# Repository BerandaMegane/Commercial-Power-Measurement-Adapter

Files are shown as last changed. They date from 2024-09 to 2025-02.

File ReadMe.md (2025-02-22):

# Commercial-Power-Measurement-Adapter

部屋のコンセントから出ている商用電源（AC100V）の周波数と電圧を測定するアダプタをマイコンで製作しました。  
Windows PC や Raspberry Pi へアダプタを USB 接続すると、仮想 COM ポートとして認識され、測定値を取得することができます。

筐体に収められた基板
回路基板

回路・マイコンプログラムは次のサイトを参考にしています。~~というかアレンジして作ってみた結果、劣化コピーになりました。~~  
* ChaN氏 [ELM - 電圧周波数測定アダプタ](http://elm-chan.org/works/lvfm/report_j.html)

Qiita にて解説しています。
* Qiita - [電源周波数測定アダプタを真似して作ってみた](https://qiita.com/BerandaMegane/items/4fd927695e5ca32714c5)

このアダプタから電源周波数の情報を取得し、可視化するプログラムはこちらです。
* [BerandaMegane/Power-Monitoring-Agent](https://github.com/BerandaMegane/Power-Monitoring-Agent)

以降は各ディレクトリの中身を解説しています。

## Circuit design 回路設計 

回路図や LTSpice シミュレーションファイル (.asc) など、アダプタの回路設計に関するファイルを置いています。  
作図ソフトウェアは BSch3V です。

* BSch3V - https://www.suigyodo.com/online/schsoft.htm
* LTSpice - https://www.analog.com/jp/resources/design-tools-and-calculators/ltspice-simulator.html

回路設計のバージョンは2つあります。

* [ver1](https://github.com/BerandaMegane/Commercial-Power-Measurement-Adapter/tree/main/CircuitDesign/ver1)
  * 製作したバージョンですが、修正したい点がいくつかあります。
* [ver2](https://github.com/BerandaMegane/Commercial-Power-Measurement-Adapter/tree/main/CircuitDesign/ver2)
  * 修正バージョンですが、製作していません。

## Board design 基板設計

ユニバーサル基板（秋月電子通商 B 基板）で製作しました。部品の配置に関するファイルを置いています。画像に載っていない部品も多いので、あんまり参考にはなりません。  
作図ソフトウェアは marmelo です。

* marmelo - https://motchy99.blog.fc2.com/blog-entry-70.html

## Program ATmega328P マイコンプログラム

制御マイコンには AVR ATmega328P を使用しており、当初は、Atmel Studio (Microchip Studio) による AVR GCC プロジェクトで製作していましたが、後日 Rust (avr-hal) に書き直しています。  
詳細は各ディレクトリの中を参考にしてください。

ビルド済みバイナリ (.elf) を使ってプログラムを書き込むときは、次を参考にしてください。

1. [Releases](https://github.com/BerandaMegane/Commercial-Power-Measurement-Adapter/releases) からバイナリをダウンロードします。
1. AVR ライターを使用し、マイコンにバイナリを書き込みます。  
AVR ライターは Arduino があれば自作することもできます。

なお、ビルド済みバイナリは、公開している回路基板で動作させる前提であり、その他の条件は次の通りです。
* 動作クロック 20MHz
  * ヒューズビット: FF. D9, FF  
  https://www.engbedded.com/fusecalc?P=ATmega328P&V_LOW=0xFF&V_HIGH=0xD9&V_EXTENDED=0xFF&O_HEX=Apply+values
* シリアル通信
  * non-parity, stop-1bit, data-8bit, 19200bps 

* Atmel Studio - https://www.microchip.com/en-us/tools-resources/develop/microchip-studio
* avr-hal - https://github.com/Rahix/avr-hal

## STL 3Dプリンタ 筐体モデル

3Dプリンタで作った筐体です。

* [top.stl](./STL/top.stl)
* [bottom.stl](./STL/bottom.stl)

## License
This project is licensed under the MIT License, see the LICENSE file for details.

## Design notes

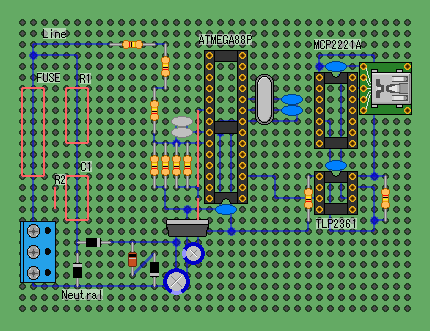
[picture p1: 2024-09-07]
BoardDesign/ver2/メイン基板_表面_ver2.bmp

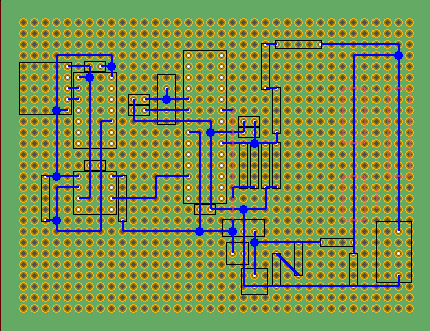
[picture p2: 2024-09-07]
BoardDesign/ver2/メイン基板_裏面_ver2.bmp

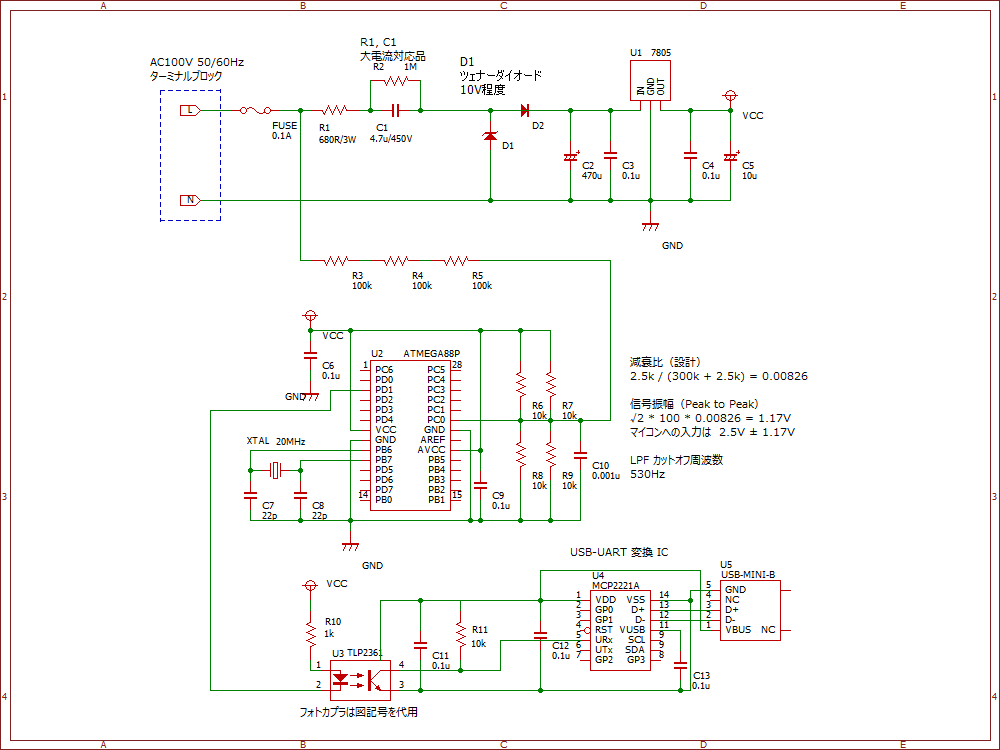
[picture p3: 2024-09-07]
CircuitDesign/ver2/circuit_ver2.png

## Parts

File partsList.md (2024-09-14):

# 部品リスト

## 基板その他
* 秋月電子 ユニバーサル基板 Bタイプ
  * https://akizukidenshi.com/catalog/g/g103230
* 2P ACコード(2Pプラグ/ハンダ仕上げコード) 1.8m
  * https://akizukidenshi.com/catalog/g/g100733/
* USBケーブル USB2.0 Type-Aオス⇔ミニBオス 1.5m A-miniB
  * https://akizukidenshi.com/catalog/g/g117014/

## 電源関係
特記事項なしは 1/4W 炭素被膜抵抗などの汎用品です。

* 20mm ヒューズホルダー マル信無線電機 MF-563
  * https://akizukidenshi.com/catalog/g/g114929/
* ガラス管ヒューズ MF51NR 250V0.2A 20mm
  * https://akizukidenshi.com/catalog/g/g107127/
* ターミナルブロック 2P 緑 縦 TB411-2-2-E-1
  * https://akizukidenshi.com/catalog/g/g106309/
* R1 不燃性酸化金属皮膜抵抗 3W220Ω
  * 回路図上は 680 Ω ですが、多少調整はできます。
  * https://akizukidenshi.com/catalog/g/g111020/
* C1 メタライズドポリプロピレンフィルムコンデンサー 4.7μF250V ルビコンMPS
  * https://akizukidenshi.com/catalog/g/g105982/
* D1 定電圧ダイオード(ツェナーダイオード) 5.6V1W RD5.6F
  * 回路図上は 10 V 程度のツェナー電圧が指定されていますが、低い電圧のものでも直列接続で 10 V 以上になれば問題ないと考えています。
  * https://akizukidenshi.com/catalog/g/g117082/
* D2 汎用整流用ダイオード 1000V1A 1N4007
  * https://akizukidenshi.com/catalog/g/g100934/
* U1 三端子レギュレーター 5V1.5A NJM7805FA
  * https://akizukidenshi.com/catalog/g/g108678/

## マイコン関係
* AVRマイコン ATMEGA328P-PU
  * https://akizukidenshi.com/catalog/g/g103142/
* 丸ピンICソケット (28P) 300mil
  * https://akizukidenshi.com/catalog/g/g101339
* クリスタル(水晶発振子) 20MHz
  * https://akizukidenshi.com/catalog/g/g108673/
* フォトカプラー GaAlAs赤外LED+フォトIC TLP2361
  * https://akizukidenshi.com/catalog/g/g111004/
* USB⇔シリアル変換IC MCP2221A-I/P
  * https://akizukidenshi.com/catalog/g/g113069/
* ブレッドボード用ミニBメスUSBコネクターDIP化キット
  * https://akizukidenshi.com/catalog/g/g105258/

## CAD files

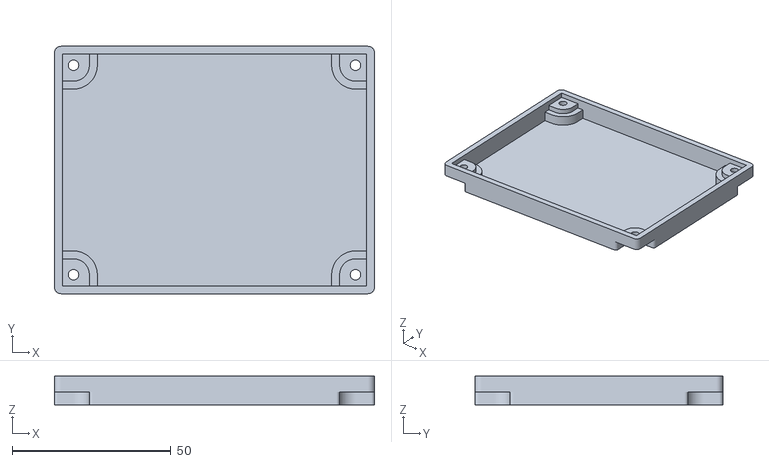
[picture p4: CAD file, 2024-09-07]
STL/bottom.stl
100.9 x 78.0 x 9.00

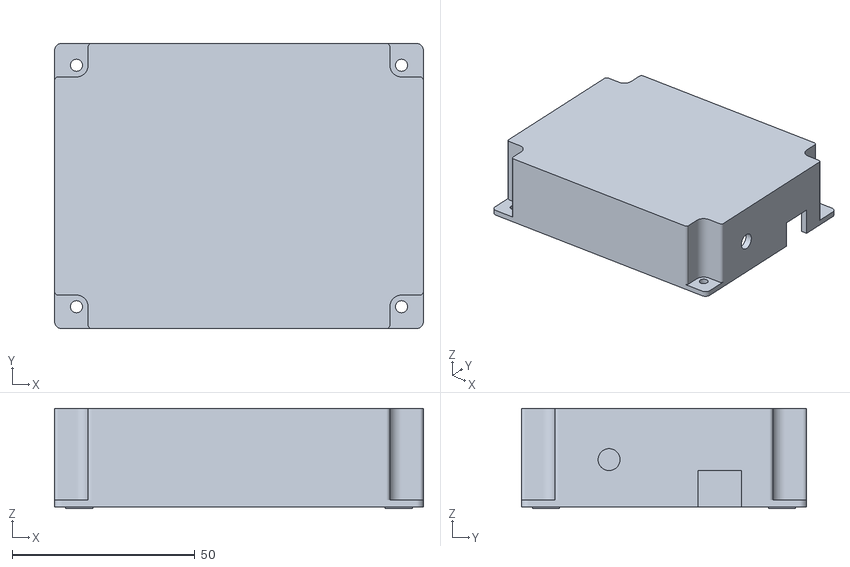
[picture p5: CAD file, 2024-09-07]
STL/top.stl
100.9 x 78.0 x 27.4

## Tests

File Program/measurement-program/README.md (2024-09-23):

# measurement-program

元々 C で書かれていた AVR マイコンプログラムを Rust で書き直しました。  
Rust (nightly) コンパイラ等が必要です。

## Build Instructions ビルド手順
1. Install prerequisites as described in the [`avr-hal` README] (`avr-gcc`, `avr-libc`).

2. Run `cargo build --relase` to build the firmware.  
The binary files will be generated in `target/avr-atmega328p/release/***/elf`.

[`avr-hal` README]: https://github.com/Rahix/avr-hal#readme

## License
This project is licensed under the MIT License, see the LICENSE.txt file for details.

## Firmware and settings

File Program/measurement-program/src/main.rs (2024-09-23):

#![no_std]
#![no_main]
#![feature(abi_avr_interrupt)]

// UART 自作
mod uart_interrupt;

// 動作クロック周波数
type CoreClock = atmega_hal::clock::MHz20;
// タイマ割り込み周波数
const TIMER1_FREQ: u32 = 1000;
// UART 通信速度
const UART_BAUDRATE: u32 = 19200;
// AD変換周期クロック
const ADC_CLOCK: f32 = 13.0;
const ADC_DIV: f32 = 128.0;
const ADC_FREQ: f32 = CoreClock::FREQ as f32 / ADC_CLOCK / ADC_DIV;

// ディレイ関係
// use atmega_hal::{clock::Clock, pac, prelude::_embedded_hal_blocking_delay_DelayMs, usart::{Baudrate, Usart}, Atmega};
use atmega_hal::clock::Clock;
use embedded_hal::delay::DelayNs;
type Delay = atmega_hal::delay::Delay<crate::CoreClock>;
#[allow(dead_code)]
fn delay_ms(ms: u16) {
    Delay::new().delay_ms(u32::from(ms))
    // embedded_hal::delay::DelayNs::delay_ms(&mut Delay::new(), u32::from(ms))
}
#[allow(dead_code)]
fn delay_us(us: u32) {
    Delay::new().delay_us(us)
}

// 測定範囲 10 - 100 Hz
// 測定中の波形立上り回数  1s ごとに -1 リセット, -1 でないときは測定中
// 測定を開始してから1秒以内にタイマ割り込みによって、測定が終了するはず
// よって、数値は電源周波数以下となるはず
static mut RISED_COUNT: i8 = -1;  // 60Hz なら 60 以下
// 測定中の計数値  1s ごとに 0 リセット
static mut ELAPSED_COUNT: u16 = 0;  // 60Hz: ADC_FREQ / 60 = 200, 10Hz: 1200
// 測定中の計数確定値  1s ごとに 0 リセット
static mut MEASURED_COUNT: u16 = 0;  // 60Hz: RISED * ELAPSED = 12000 (ほぼ ADC_FREQ)
// 1秒計測用カウンタ
static mut TIMER_1S_COUNTER: u16 = 0;  // 0..1000
// 60秒計測用カウンタ
static mut TIMER_60S_COUNTER: u8 = 0;  // 0..60

// 分圧抵抗値
const DAMP_A: f32 = 5.0;
const DAMP_B: f32 = 300.0;
// 分圧抵抗による減衰比 1次側を1としたときの2次側比率
const DAMPLING_RATIO: f32 = DAMP_A / (DAMP_B + DAMP_A);

// 波形取得するサンプル数 >= ADC_FREQ / 40Hz = 300
mod my_queue;
pub use my_queue::RingBufferIndex16bit;
const WAVEFORM_MAX: usize = 512;
static mut WAVEFORM_BUF: RingBufferIndex16bit<u16, WAVEFORM_MAX> = RingBufferIndex16bit::new(WAVEFORM_MAX);

// 波形補正値
static mut WAVE_OFFSET: f32 = 512.0;
// 2乗した電圧値の累計値 (実効値)
static mut ALL_CYCLE_SQUARE_SUM: f32 = 0.0;
// 電圧値の累計値 (平均値)
static mut ALL_CYCLE_AVERAGE: f32 = 0.0;

// メイン関数 エントリポイント
#[atmega_hal::entry]
fn main() -> ! {
    // ペリフェラルの取得
    let dp = unsafe {atmega_hal::Peripherals::steal()};

    // 各種初期化
    port_init();
    timer1_init();
    adc_init();
    adc_start();
    uart_interrupt::init(CoreClock::FREQ, UART_BAUDRATE);
    
    // 全割り込み許可
    unsafe {avr_device::interrupt::enable();}  // sei();

    uart_interrupt::send_str_line("mode,data1,data2");
    
    unsafe {
        let mut buf: [u8; 16] = [0; 16];

        loop {
            // sync 同期
            const CSV2_BEGIN: u8 = 3;
            while TIMER_60S_COUNTER < CSV2_BEGIN {
                avr_device::asm::nop();
            }

            // while ! WAVEFORM_VEC.is_empty() {
            while ! WAVEFORM_BUF.is_empty() {
                // CSV line 2 start
                uart_interrupt::send_str("csv-2");
                
                // index
                uart_interrupt::send_str(",");
                // uart_interrupt::send_str(u32_to_str(WAVEFORM_VEC.len() as u32, &mut buf));
                uart_interrupt::send_str(u32_to_str(WAVEFORM_BUF.len() as u32, &mut buf));
                
                // waveform
                uart_interrupt::send_str(",");
                // uart_interrupt::send_str(u32_to_str(WAVEFORM_VEC.pop().unwrap() as u32, &mut buf));
                uart_interrupt::send_str(u32_to_str(WAVEFORM_BUF.dequeue() as u32, &mut buf));
                
                // 改行
                uart_interrupt::send_str("\n");
        
                delay_ms(20);
            }

            // sync
            while TIMER_60S_COUNTER != 0 {
                avr_device::asm::nop();
            }
        }
    }
}


// タイマ1 比較A 割り込みハンドラ
// note: VSCode の rust-analyzer が赤線を出すため、別関数に分割
#[avr_device::interrupt(atmega328p)]
fn TIMER1_COMPA() {
    timer1_compa_proc();
}

fn timer1_compa_proc() {
    unsafe {
        // 1 sec 周期
        if TIMER_1S_COUNTER < 1000 {
            TIMER_1S_COUNTER += 1;
            return;
        } else {
            TIMER_1S_COUNTER = 0;
        }

        // 60 sec 周期
        if TIMER_60S_COUNTER < 60 {
            TIMER_60S_COUNTER += 1;
        } else {
            TIMER_60S_COUNTER = 0;
        }
    }

    timer_interrupt_1s();
}

fn timer_interrupt_1s() {
    // ペリフェラル取得
    let dp = unsafe {atmega_hal::Peripherals::steal()};

    unsafe {
        // LED 反転
        dp.PORTB.portb.modify(|r, w| w.pb5().bit(! r.pb5().bit()));

        // 周波数測定
        let mut freq: f32 = 0.0;
        if MEASURED_COUNT > 0 {
            freq = RISED_COUNT as f32 * ADC_FREQ / MEASURED_COUNT as f32;
        }
        
        // 電圧測定
        let mut rms: f32 = 0.0;
        if MEASURED_COUNT > 0 {
            let temp_rms = sqrt_newton(ALL_CYCLE_SQUARE_SUM as f32 / MEASURED_COUNT as f32);
            rms = (temp_rms / 1024.0 * 5.0) / DAMPLING_RATIO;
        }

        // 割り込み許可
        avr_device::interrupt::enable();  // sei();
        
        // 出力
        uart_interrupt::send_str("csv-1,");
        let mut buf: [u8; 32] = [0; 32];

        // 周波数
        uart_interrupt::send_str(f32_to_str(freq, 4, &mut buf));
        uart_interrupt::send_str(",");
        // 電圧
        uart_interrupt::send_str(f32_to_str(rms, 3, &mut buf));

        // // rised_count
        // uart_interrupt::send_str(i32_to_str(RISED_COUNT as i32, &mut buf));
        // uart_interrupt::send_str(",");
        // // measured_count
        // uart_interrupt::send_str(u32_to_str(MEASURED_COUNT as u32, &mut buf));
        // uart_interrupt::send_str(",");
        // // WAVE_OFFSET
        // uart_interrupt::send_str(f32_to_str(WAVE_OFFSET, 3, &mut buf));
        // uart_interrupt::send_str(",");

        // // ALL_CYCLE_SQUARE_SUM
        // uart_interrupt::send_str(f32_to_str(ALL_CYCLE_SQUARE_SUM, 1, &mut buf));
        // uart_interrupt::send_str(",");

        // 改行
        uart_interrupt::send_str("\n");

        // オフセット値の算出
        WAVE_OFFSET = WAVE_OFFSET * 0.95 + ALL_CYCLE_AVERAGE * 0.05;

        // 測定リセット、次回の立ち上がりから測定開始
        RISED_COUNT = -1;
    }
}

#[avr_device::interrupt(atmega328p)]
fn ADC() {
    /* ADC 割り込みベクタ
     * 
     * ADC 終了後、実行される割り込み処理
     */

    let dp = unsafe {atmega_hal::Peripherals::steal()};
    
    unsafe {
        // ADC値
        let adc_raw_val = dp.ADC.adc.read().bits();
        // 波形正負極性  true: 正, false: 負
        let threshold = WAVE_OFFSET as u16;
        let current_polarity = adc_raw_val > threshold;
        // 前回計測時の正負極性
        static mut PRE_POLARITY: bool = false;
        // 波形立ち上がりフラグ  1: 立ち上がり
        let is_wave_rising = 
            ! PRE_POLARITY
            && current_polarity 
            && adc_raw_val < (threshold + 25);  // 初回測定誤差を減らすため
        PRE_POLARITY = current_polarity;
        
        // 計数値の処理
        if is_wave_rising {
            // 波形立上りを検出したら計数値リセットし、測定開始
            if RISED_COUNT == -1 {
                RISED_COUNT = 0;
                ELAPSED_COUNT = 0;
                MEASURED_COUNT = 0;
            } else {
                RISED_COUNT += 1;
                MEASURED_COUNT = ELAPSED_COUNT;
            }
        }
        ELAPSED_COUNT += 1;
        
        // 波形取得
        if TIMER_60S_COUNTER == 1 {
            // 60 sec カウンタが 1 のとき (0-indexed)
            
            if RISED_COUNT == 0 && ! WAVEFORM_BUF.is_full() {
                // 1周期目の波形取得
                WAVEFORM_BUF.enqueue(adc_raw_val);
            }
        }
        
        // 電圧の 実効値 and 平均 測定
        // 1周期分の2乗値の総和
        static mut CYCLE_SQUARE_SUM: f32 = 0.0;
        CYCLE_SQUARE_SUM += (adc_raw_val as f32 - WAVE_OFFSET) * (adc_raw_val as f32 - WAVE_OFFSET);
        
        // 1周期分の総和
        static mut CYCLE_VAL_SUM: u32 = 0;
        CYCLE_VAL_SUM += adc_raw_val as u32;

        if is_wave_rising {
            // 波形立ち上がり時
            
            if RISED_COUNT == 0 {
                // 1周期目
                
                // 2乗値の総和
                CYCLE_SQUARE_SUM = 0.0;
                ALL_CYCLE_SQUARE_SUM = 0.0;
                
                // 総和
                CYCLE_VAL_SUM = 0;
            } else {
                // 2周期目以降
                
                // 2乗値の総和
                ALL_CYCLE_SQUARE_SUM += CYCLE_SQUARE_SUM;
                CYCLE_SQUARE_SUM = 0.0;

                ALL_CYCLE_AVERAGE = if MEASURED_COUNT != 0 {
                    CYCLE_VAL_SUM as f32 / MEASURED_COUNT as f32
                } else {
                    512.0
                }
            }
        }
    }
}

// パニックハンドラ
#[cfg(not(doc))]
#[panic_handler]
fn panic(_info: &core::panic::PanicInfo) -> ! {
    // 割り込み無効
    avr_device::interrupt::disable();
    let dp = unsafe {atmega_hal::Peripherals::steal()};
    loop {
        const BLINK_HZ: u32 = 10;
        avr_device::asm::delay_cycles(CoreClock::FREQ / BLINK_HZ / 2);
        dp.PORTB.portb.modify(|_, w| w.pb4().set_bit());
        avr_device::asm::delay_cycles(CoreClock::FREQ / BLINK_HZ / 2);
        dp.PORTB.portb.modify(|_, w| w.pb4().clear_bit());
    }
}

// GPIO 初期化
fn port_init() {
    let dp = unsafe {atmega_hal::Peripherals::steal()};
    let pins = atmega_hal::pins!(dp);
    
    /* 
     * Port B
     *   PB0 - 3: No Connect
     *   PB4: Debug (Panic)
     *   PB5: Debug
     *   PB6: No Connect
     */
    pins.pb5.into_output();
    pins.pb4.into_output();
    
    /* 
     * Port C
     *   PC0: ADC0 (AC wave input)
     *   PC1 - 5: No Connect
     */
    pins.pc0.into_floating_input();

    /* 
     * Port D
     *   PD0: No Connect
     *   PD1: TxD (output)
     *   PD2 - 7: No Connect
     */
    pins.pd1.into_output();
}

// Timer1 初期設定
fn timer1_init() {
    let dp = unsafe {atmega_hal::Peripherals::steal()};

    // カウント値の算出
    let ticks = (CoreClock::FREQ / TIMER1_FREQ - 1) as u16;

    // カウント値クリア
    dp.TC1.tcnt1.write(|w| w.bits(0));
    // 比較値
    dp.TC1.ocr1a.write(|w| w.bits(ticks));
    // CTCモード 分周なし 直接カウント
    dp.TC1.tccr1a.write(|w| w.wgm1().bits(0));
    dp.TC1.tccr1b.write(|w| w.wgm1().bits(1));
    // タイマ比較A 割り込み許可
    dp.TC1.timsk1.write(|w| w.ocie1a().set_bit());
    // タイマカウントスタート
    dp.TC1.tccr1b.modify(|_, w| w.cs1().direct());
}


// ADC 初期化関数
fn adc_init() {
    let dp = unsafe {atmega_hal::Peripherals::steal()};

    // 基準電圧 AVCC, 右寄せ(ADLAR = 0), ADC0
    dp.ADC.admux.write(|w| 
        w
        .refs().avcc()  // 基準電圧 AVCC
        .adlar().clear_bit()  // 右寄せ
        .mux().adc0()  // ADC
    );

    // AD許可, AD連続変換, AD変換完了割り込み許可, 128分周
    dp.ADC.adcsra.write(|w| 
        w
        .aden().set_bit()  // AD許可
        .adie().set_bit()  // AD変換完了割り込み許可
        .adate().set_bit()  // AD連続変換
        .adps().prescaler_128()  // 128分周
    );

    dp.ADC.adcsrb.write(|w| 
        w.adts().val_0x00()
    );
}

// ADC 変換開始
fn adc_start() {
    let dp = unsafe {atmega_hal::Peripherals::steal()};
    dp.ADC.adcsra.modify(|_, w| {
        w
        .adsc().set_bit() // AD変換開始
    });
}

// 平方根を求める関数  by ChatGPT
fn sqrt_newton(x: f32) -> f32 {
    if x < 0.0 {
        return f32::NAN; // 負の数の場合は NaN を返す
    }
    
    let mut guess = x / 2.0;
    let mut prev_guess = 0.0;

    // 収束するまで繰り返す
    while abs_f32(guess - prev_guess) > 0.00001 {
        prev_guess = guess;
        guess = (guess + x / guess) / 2.0;
    }

    guess
}


// 浮動小数点数を10進数文字列に変換する関数
fn f32_to_str<'a>(value: f32, after: u8, buf: &'a mut [u8]) -> &'a str {
    // ポインタ
    let mut ptr: u8 = 0;
    
    
    for i in 0..buf.len() {
        buf[i] = 0;
    }
    
    if value < 0.0 {
        buf[ptr as usize] = "-".as_bytes()[0];
        ptr += 1;
    }
    
    let mut n = abs_f32(value);
    
    // 整数部分の変換
    let mut integer = n as u32;
    for _i in 0..buf.len()-1 {
        let r = integer % 10;
        let c: u8 = "0".as_bytes()[0] + r as u8;

        buf[ptr as usize] = c;
        ptr += 1;

        integer /= 10;
        if integer == 0 {
            break;
        }
    }
    reverse(buf, 0, ptr.saturating_sub(1));

    // 小数点
    buf[ptr as usize] = ".".as_bytes()[0];
    ptr += 1;

    // 小数の変換
    let mut decimal: f32 = n % 1.0;
    for _i in 0..after {
        decimal *= 10.0;
        let r = decimal as u8;
        let c: u8 = "0".as_bytes()[0] + r as u8;
        buf[ptr as usize] = c;
        ptr += 1;

        decimal %= 1.0;
    }

    return match byte_array_to_str(buf) {
        Ok(s) => { s }
        Err(_s) => { "" }
    };
}

// 符号なし整数を10進数文字列に変換する関数
#[allow(dead_code)]
fn u32_to_str<'a>(value: u32, buf: &'a mut [u8]) -> &'a str {
    let mut ptr: u8 = 0;
    
    // 初期化
    for i in 0..buf.len() {
        buf[i] = 0;
    }
    // 変換
    let mut n = value;
    for _i in 0..buf.len()-1 {
        let r = n % 10;
        let c: u8 = 0x30 + r as u8;  // 0x30 = '0'

        buf[ptr as usize] = c;
        ptr += 1;

        n /= 10;
        if n == 0 {
            break;
        }
    }
    reverse(buf, 0, ptr-1);
    buf[ptr as usize] = 0x00;

    return match byte_array_to_str(buf) {
        Ok(s) => { s }
        Err(_s) => { "" }
    };
}

// 整数を10進数文字列に変換する関数
#[allow(dead_code)]
fn i32_to_str<'a>(value: i32, buf: &'a mut [u8]) -> &'a str {
    let mut ptr: u8 = 0;
    
    // 初期化
    for i in 0..buf.len() {
        buf[i] = 0;
    }
    
    // 符号
    let is_minus = value < 0;
    if is_minus {
        buf[ptr as usize] = "-".as_bytes()[0];
        ptr += 1;
    }

    // 変換
    let mut n: u32 = if ! is_minus { value as u32 } else { (-value) as u32 };
    for _i in 0..buf.len()-1 {
        let r = n % 10;
        let c: u8 = 0x30 + r as u8;  // 0x30 = '0'

        buf[ptr as usize] = c;
        ptr += 1;

        n /= 10;
        if n == 0 {
            break;
        }
    }
    
    if is_minus {
        reverse(buf, 1, ptr-1);
    } else {
        reverse(buf, 0, ptr-1);
    }
    buf[ptr as usize] = 0x00;

    return match byte_array_to_str(buf) {
        Ok(s) => { s }
        Err(_s) => { "" }
    };
}

pub fn byte_array_to_str(bytes: &[u8]) -> Result<&str, &'static str> {
    // ヌル終端 (0) の位置を探す
    let nul_pos = bytes.iter().position(|&b| b == 0).ok_or("No null terminator found")?;

    // ヌル終端までのバイト列を &str に変換
    core::str::from_utf8(&bytes[..nul_pos]).map_err(|_| "Invalid UTF-8 sequence")
}

fn reverse(buf: &mut [u8], mut i: u8, mut j: u8) {
    while i < j {
        // swap(&mut buf[i], &mut buf[j]);
        buf.swap(i as usize, j as usize);
        i += 1;
        j = j.saturating_sub(1);
    }
}

// 絶対値を求める関数  by ChatGPT
fn abs_f32(x: f32) -> f32 {
    if x > 0.0 {
        return x;
    } else {
        return -x;
    }
}

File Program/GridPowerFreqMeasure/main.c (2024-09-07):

/*
 * GridPowerFreqMeasure
 * Author : user
 * 
 * # マイコンについて
 * ## MCU
 * AVR ATmega328P
 * 
 * ## Fuse Bit
 * LOW:      0xF7
 * HIGH:     0xD1
 * EXTENDED: 0xFF
 * 
 * ## Frequency
 * XTAL:  20 MHz
 * CPU:   20 MHz
 * 
 * # ソフトウェアについて
 * ## サンプリング
 * ADC連続変換モードを利用してサンプリングしています。
 * サンプリング周波数 f_s = F_CPU / ADC_DIV / ADC_CLOCK = 約 12 kHz
 * 
 * ## 周波数測定
 * 入力信号の周期を測定して周波数に換算するレシプロカル方式で周波数を測定しています。
 * 電源周波数のように低い周波数を測定する場合によく利用されます。
 * ある測定時間のおける入力信号の周波数は、次のように求められます。
 * 
 * 入力信号の周期数 cycles, サンプリング周波数 f_s, サンプリング数 count とすると次のようになります。
 *   入力信号周波数 = cycles / (count / f_s) [Hz]
 * 
 * この方式で周波数測定するときの分解能は、次のように求められます。
 * 
 * 入力信号周期 f_in, サンプリング周期 f_s, 測定時間 T とすると次のようになります。
 *   周波数分解能 = f_in / f_s / T [Hz]
 * 
 * 本プログラムで用いる値を代入し、f_s = 12 [kHz], T = 1 [s] のとき、
 * 次のようになります。
 * 
 *   f_in = 50 [Hz] のとき分解能 = 0.00417 [Hz] (4.17 [mHz])
 *   f_in = 60 [Hz] のとき分解能 = 0.00500 [Hz] (5.00 [mHz])
 * 
 * ## 電圧測定
 * 電圧値は実効値の定義に従い、入力信号1周期分の瞬時値に対して、
 * 2乗 → 総和平均 → 平方根をとることによって求めます。
 * 
 * # 参考資料
 * ## 回路全体
 * http://elm-chan.org/works/lvfm/report_j.html
 * ## レシプロカル方式
 * https://www.keisoku.co.jp/md/support/useful/u_about-aa/u_counter/
 * 
 */

// CPU 動作周波数 (delay.h に必要)
#define F_CPU 20000000UL

#include <stdio.h>
#include <stdint.h>
#include <stdlib.h>
#include <math.h>

#include <avr/io.h>
#include <avr/interrupt.h>
#include <util/delay.h>

// 自作 UART ライブラリ
#include "avr_uart.h"

// GPIO 初期化関数
void port_init(void);

// UART ボーレート周波数
#define UART_BAUD (19200)

// タイマ割り込み周波数
#define TIMER_FREQ (1000)
// タイマ 初期化関数
void timer_init(void);

// AD変換周波数の分周値
#define ADC_DIV (128)
// AD変換周期クロック
#define ADC_CLOCK (13)
// 分圧抵抗による減衰比 1次側を1としたときの2次側比率
#define DAMPLING_RATIO (5.0 / (300.0 + 5.0))

// 波形取得するサンプル数
// WAVEFORM_POINTS >= 最低値,  最低値 = 20MHz / ADC_DIV / ADC_CLOCK / 40Hz = 300
#define WAVEFORM_POINTS (320)
// 波形格納データ型
typedef uint16_t adc_raw_t;
// 波形配列
volatile adc_raw_t waveform[WAVEFORM_POINTS];
// 波形ポイント数
volatile uint16_t waveform_len = 0;

// 電圧2乗値の累計値
volatile uint64_t all_cycle_square_sum = 0;

// 波形補正値
volatile float wave_offset = 512;

volatile float all_cycle_average;

// ADC 初期化関数
void adc_init(void);
// ADC 連続変換開始
void adc_start(void);

// 測定中の波形立上り回数  1s ごとに -1 リセット, -1 でないときは測定中
volatile int8_t   rised_count = -1;
// 測定中の計数値         1s ごとに 0 リセット
volatile uint16_t elapsed_count = 0;
// 測定中の計数確定値     1s ごとに 0 リセット
volatile uint16_t measured_count = 0;

volatile uint8_t  timer_60s_counter = 0;

// 波形CSV形式出力関数
uint8_t waveform_csv(const uint16_t start, const uint8_t count) {
    /*
     * Arguments:
     *   start: 出力添字番号 (0 - *)
     *   count: 出力個数
     * Return:
     *   最後の値まで出力し終えたときは 1
     *   まだ出力できる値があるときは 0 
     */
    uint16_t end = start + count;
    uint16_t i = start;
    
    while (i < end && i < WAVEFORM_POINTS) {
        if (i >= waveform_len) {
            return 1;
        }
        // CSV line 2 start
        uart_send_str("csv-2");

        // index
        uart_send_str(",");
        uart_send_int(i);

        // waveform
        uart_send_str(",");
        uart_send_int(waveform[i]);
        uart_send_str("\n");
        
        i++;
    }
    return 0;
}

void clear_waveform(void) {
    for (int i = 0; i < WAVEFORM_POINTS; i++) {
        waveform[i] = 0;
    }
}

int main(void) {
    // 各種初期化
    port_init();
    timer_init();
    adc_init();
    adc_start();
    uart_init(F_CPU, UART_BAUD);
    
    // 全割り込み有効化
    sei();

    // CSV ヘッダ情報出力
    uart_send_str("\nmode, data1, data2\n");

    const int block_size = 8;
    const int block_count = WAVEFORM_POINTS / block_size;
    while (1) {
        int counter = 2;
		
		for (int i = 0; i < block_count; i++) {
            while (timer_60s_counter != counter);
            if (waveform_csv(block_size * i, block_size))  break;
            counter++;
		}

        clear_waveform();
    }
}

ISR(TIMER1_COMPA_vect) {
    /**
     * タイマ1 COMPA タイマ割り込みベクタ
     * 
     * 1 ms ごとに実行する
     */
    static uint16_t timer_1s_counter = 0;
    timer_1s_counter++;
    
    if (timer_1s_counter / 1000) {
        // 1 sec 周期
        timer_1s_counter = 0;

        // CSV line 1 start
        uart_send_str("csv-1");

        // // rised_count
        // uart_send_int(rised_count);

        // // measured_count
        // uart_send_str(",");
        // uart_send_int(measured_count);

        // 周波数測定
        float freq = 0;
        if (measured_count != 0) {
            freq = (float)rised_count / (measured_count / ((float)F_CPU / ADC_DIV / ADC_CLOCK));
        }

        // 電圧測定
        float rms = 0;
        if (measured_count != 0) {
            const float temp_rms = sqrt((float)all_cycle_square_sum / measured_count);
            rms = (temp_rms / 1024.0 * 5.0) / DAMPLING_RATIO;
        }
        
        char buf_str[32];

        // 周波数出力
        uart_send_str(",");
        dtostrf(freq, 0, 3, buf_str);
        uart_send_str(buf_str);

        // 電圧値出力
        uart_send_str(",");
        dtostrf(rms, 0, 2, buf_str);
        uart_send_str(buf_str);

        // 平均電圧値出力
        uart_send_str(",");
        dtostrf(wave_offset, 4, 2, buf_str);
        uart_send_str(buf_str);

        uart_send_str("\n");

        // オフセット値の算出
        wave_offset = wave_offset * 0.95 + all_cycle_average * 0.05;

        // 測定リセット、次回の立ち上がりから測定開始
        rised_count = -1;

        timer_60s_counter++;
        if (timer_60s_counter / 60) {
            timer_60s_counter = 0;
        }
    }
}
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

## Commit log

2024-09-07 releases によるバイナリ配布を追加
2024-09-07 リンクを修正
2024-09-07 Qiita リンクを追加
2024-09-14 ReadMe 微修正とパーツリスト追加
2024-09-15 基板サイズの誤りを修正
2025-02-22 可視化プログラムを追加
